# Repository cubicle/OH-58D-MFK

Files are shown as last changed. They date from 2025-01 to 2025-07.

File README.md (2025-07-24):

# OH-58D-MFK

[][cc-by-nc-sa]

<p align="center">
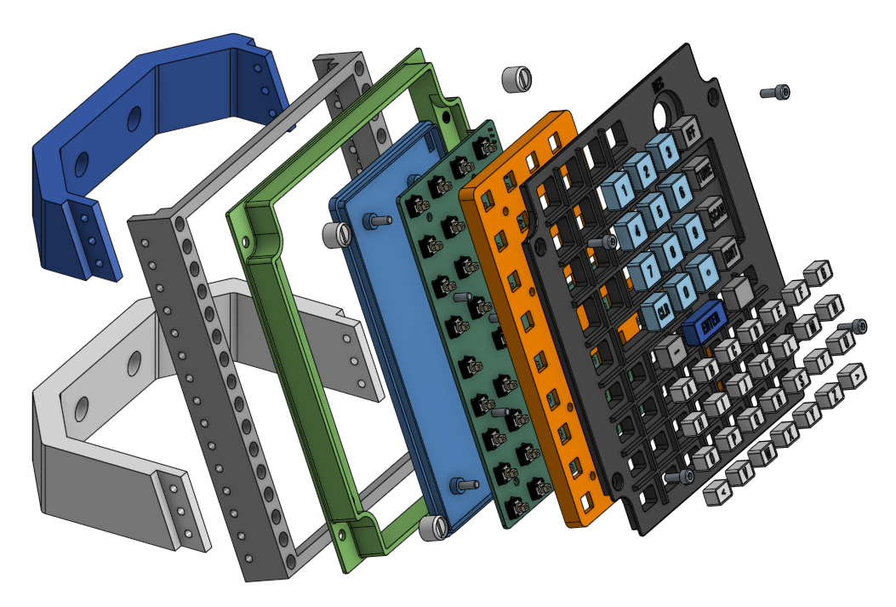
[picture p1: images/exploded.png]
Exploded view
  
</p>

## Work in progress

This project is still work in progress. Print and assemble at your own risk.

## BOM

-  1 x [Arduino Uno](https://www.amazon.de/Arduino-A000066-UNO-Rev3/dp/B008GRTSV6)
- 15 x [Heat Set Inserts M3x3 (short)](https://cnckitchen.store/products/heat-set-insert-m3-x-3-short-version-100-pieces)
-  4 x Heat Set Inserts M4
- 51 x [Diode SMD 0805 1N4148](https://www.ebay.de/itm/312738927547)
-  9 x [Resistor SMD 0805 10K](https://www.ebay.de/itm/362412320635)
- 47 x [OMRON B3F-115x Tactile Switch](https://www.ebay.de/itm/231954583799)
-  2 x [Switch cover](https://www.reichelt.de/de/de/shop/produkt/sicherheitsabdeckungen_fuer_kippschalter-105434)
-  2 x [Switch ON/OFF](https://www.pollin.de/p/kippschalter-kn3-c-101a-1-polig-on-off-420068)
-  1 x [Switch (ON)/OFF/(ON)](https://www.pollin.de/p/kippschalter-kn3-c-101a-1-polig-on-off-420068)
-  Break away pin headers
-  Wire
-  [Dupont crimping tool and connectors](https://www.amazon.de/dp/B07QX51F3B)
- 10 x Screw M3x0.50 x 8
-  5 x Screw M3x0.50 x 12

## 3D printed parts

### STLs

STLs are hosted on [Printables](https://www.printables.com/model/1201023-oh-58d-mfk).

### CAD

You can find the CAD files on [Onshape](https://cad.onshape.com/documents/6787d83c44a91f8cde39e86e/w/96151ec904b149525745d522/e/fceb9b6b394f6e8ffc93c401). Be careful as these may contain untested changes.

### Arduino Uno Case

You will need to print a case for the Arduino Uno. I used the [Arduino Uno Case](https://www.printables.com/model/122097-arduino-uno-case) from [Kazik](https://www.printables.com/@Kazik).

## License

Except where otherwise noted, this work © 2025 is licensed under a [Creative Commons Attribution-NonCommercial-ShareAlike 4.0 International License][cc-by-nc-sa].

[][cc-by-nc-sa]

[cc-by-nc-sa]: http://creativecommons.org/licenses/by-nc-sa/4.0/
[cc-by-nc-sa-image]: https://licensebuttons.net/l/by-nc-sa/4.0/88x31.png
[cc-by-nc-sa-shield]: https://img.shields.io/badge/License-CC%20BY--NC--SA%204.0-lightgrey.svg

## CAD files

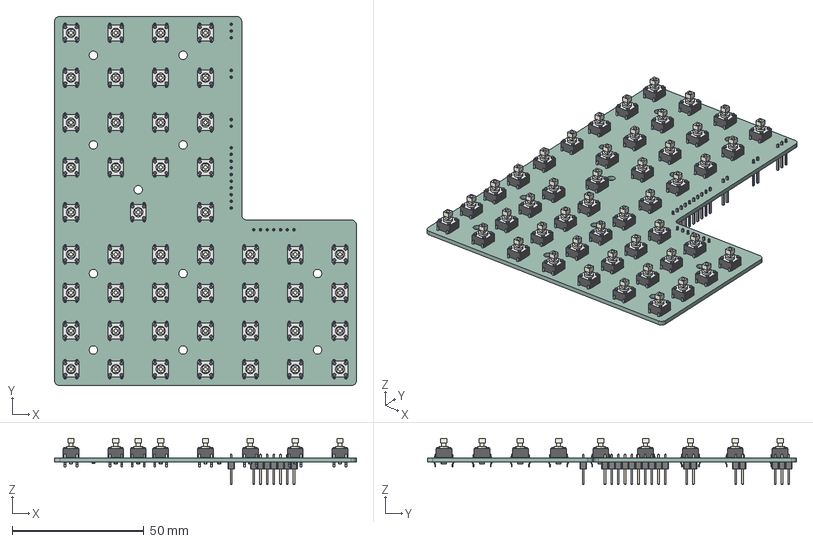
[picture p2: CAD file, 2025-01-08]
pcb/OH-58D MFK.step
114.5 x 140.0 x 17.5 mm
b3f-1050_1 x 47
D_0805 x 51
PinHeader_1x07_P254mm_Vertical
R_0805_2012Metric x 9
PinHeader_1x10_P254mm_Vertical
PinHeader_1x03_P254mm_Vertical
PinHeader_1x02_P254mm_Vertical x 2
OH-58D MFK_PCB

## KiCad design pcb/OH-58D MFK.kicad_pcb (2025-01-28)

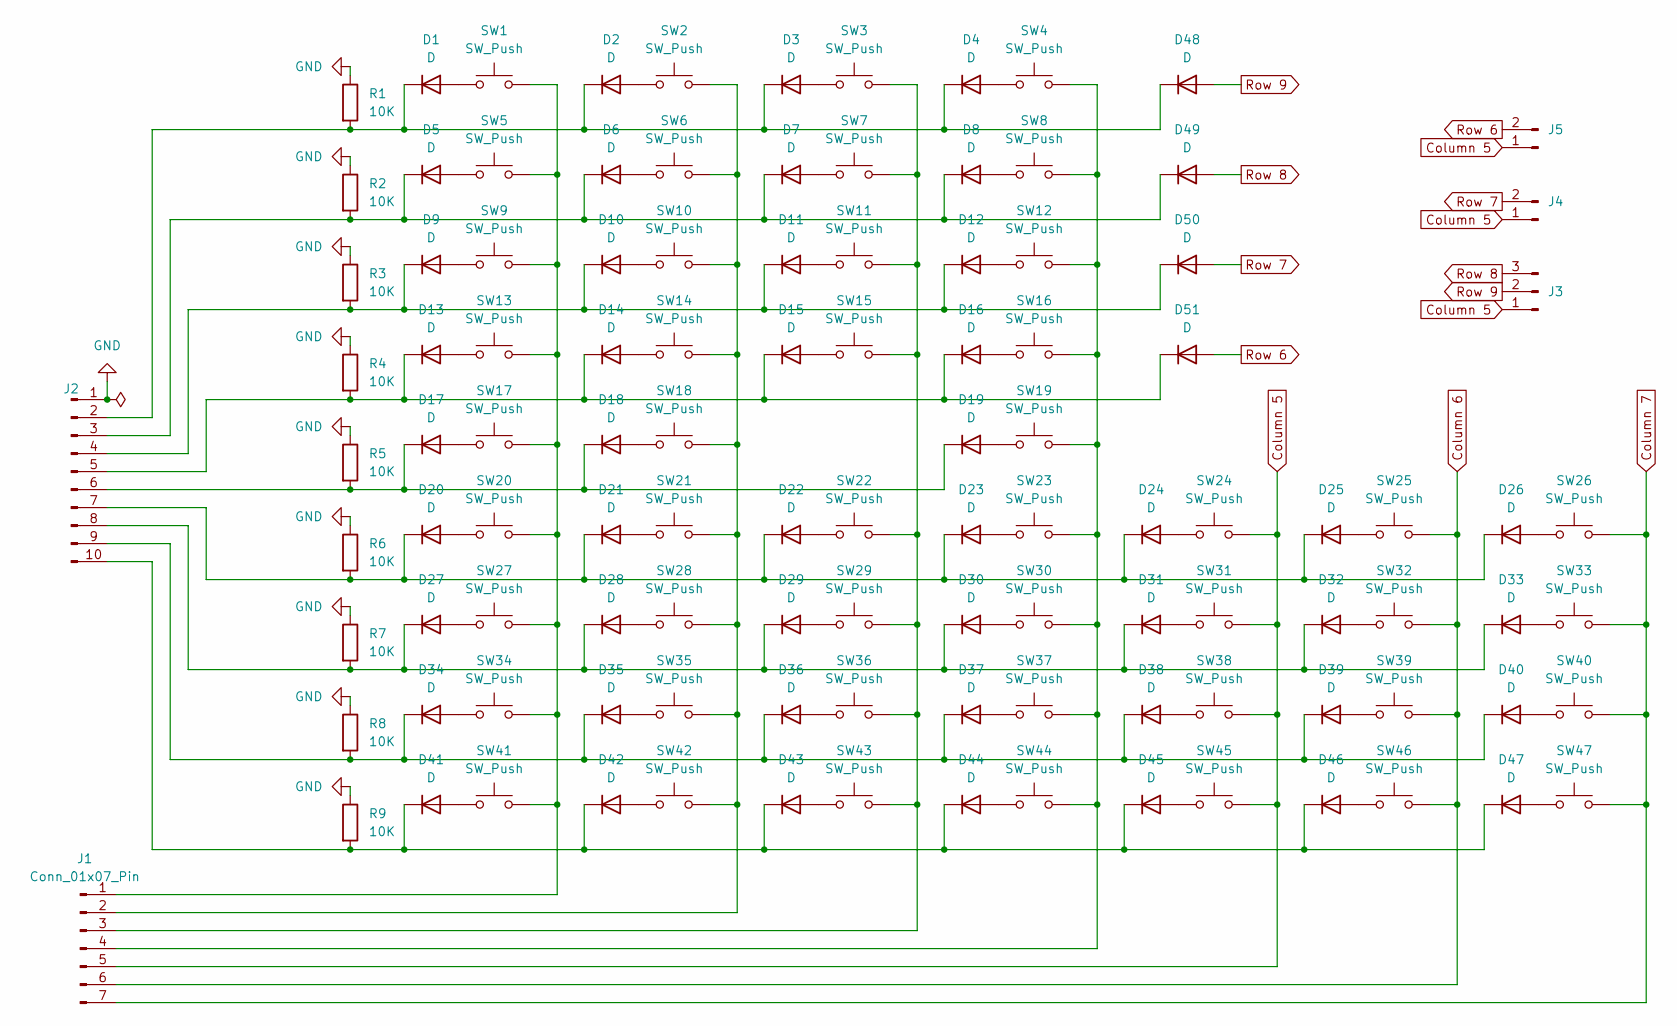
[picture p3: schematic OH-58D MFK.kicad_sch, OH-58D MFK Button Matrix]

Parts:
D1, D2, D3, D4, D5, D6, D7, D8, D9, D10, D11, D12, D13, D14, D15, D16, D17, D18, D19, D20, D21, D22, D23, D24, D25, D26, D27, D28, D29, D30, D31, D32, D33, D34, D35, D36, D37, D38, D39, D40, D41, D42, D43, D44, D45, D46, D47, D48, D49, D50, D51: D; D_0805_2012Metric_Pad1.15x1.40mm_HandSolder
J1: Conn_01x07_Pin; PinHeader_1x07_P2.54mm_Vertical
J2: Conn_01x10_Pin; PinHeader_1x10_P2.54mm_Vertical
J3: Conn_01x03_Pin; PinHeader_1x03_P2.54mm_Vertical
J4, J5: Conn_01x02_Pin; PinHeader_1x02_P2.54mm_Vertical
R1, R2, R3, R4, R5, R6, R7, R8, R9: 10K; R_0805_2012Metric_Pad1.20x1.40mm_HandSolder
SW1, SW2, SW3, SW4, SW5, SW6, SW7, SW8, SW9, SW10, SW11, SW12, SW13, SW14, SW15, SW16, SW17, SW18, SW19, SW20, SW21, SW22, SW23, SW24, SW25, SW26, SW27, SW28, SW29, SW30, SW31, SW32, SW33, SW34, SW35, SW36, SW37, SW38, SW39, SW40, SW41, SW42, SW43, SW44, SW45, SW46, SW47: SW_Push; SW_TH_Tactile_Omron_B3F-105x

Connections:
Column 5: J1.5, J3.1, J4.1, J5.1, SW24.2, SW31.2, SW38.2, SW45.2
Column 6: J1.6, SW25.2, SW32.2, SW39.2, SW46.2
Column 7: J1.7, SW26.2, SW33.2, SW40.2, SW47.2
GND: J2.1, R1.1, R2.1, R3.1, R4.1, R5.1, R6.1, R7.1, R8.1, R9.1
unnamed: D1.2 (A), SW1.1
unnamed: D1.1 (K), D2.1 (K), D3.1 (K), D4.1 (K), D48.1 (K), J2.2, R1.2
unnamed: D2.2 (A), SW2.1
unnamed: D3.2 (A), SW3.1
unnamed: D4.2 (A), SW4.1
unnamed: D5.2 (A), SW5.1
unnamed: D6.2 (A), SW6.1
unnamed: D7.2 (A), SW7.1
unnamed: D8.2 (A), SW8.1
unnamed: D9.2 (A), SW9.1
unnamed: D10.2 (A), SW10.1
unnamed: D9.1 (K), D10.1 (K), D11.1 (K), D12.1 (K), D50.1 (K), J2.4, R3.2
unnamed: D11.2 (A), SW11.1
unnamed: D12.2 (A), SW12.1
unnamed: D13.2 (A), SW13.1
unnamed: D13.1 (K), D14.1 (K), D15.1 (K), D16.1 (K), D51.1 (K), J2.5, R4.2
unnamed: D14.2 (A), SW14.1
unnamed: D15.2 (A), SW15.1
unnamed: D16.2 (A), SW16.1
unnamed: D17.2 (A), SW17.1
unnamed: D17.1 (K), D18.1 (K), D19.1 (K), J2.6, R5.2
unnamed: D18.2 (A), SW18.1
unnamed: D19.2 (A), SW19.1
unnamed: D20.2 (A), SW20.1
unnamed: D20.1 (K), D21.1 (K), D22.1 (K), D23.1 (K), D24.1 (K), D25.1 (K), D26.1 (K), J2.7, R6.2
unnamed: D21.2 (A), SW21.1
unnamed: D22.2 (A), SW22.1
unnamed: D23.2 (A), SW23.1
unnamed: D24.2 (A), SW24.1
unnamed: D25.2 (A), SW25.1
unnamed: D26.2 (A), SW26.1
unnamed: D27.2 (A), SW27.1
unnamed: D27.1 (K), D28.1 (K), D29.1 (K), D30.1 (K), D31.1 (K), D32.1 (K), D33.1 (K), J2.8, R7.2
unnamed: D28.2 (A), SW28.1
unnamed: D29.2 (A), SW29.1
unnamed: D30.2 (A), SW30.1
unnamed: D31.2 (A), SW31.1
unnamed: D32.2 (A), SW32.1
unnamed: D33.2 (A), SW33.1
unnamed: D34.2 (A), SW34.1
unnamed: D34.1 (K), D35.1 (K), D36.1 (K), D37.1 (K), D38.1 (K), D39.1 (K), D40.1 (K), J2.9, R8.2
unnamed: D35.2 (A), SW35.1
unnamed: D36.2 (A), SW36.1
unnamed: D37.2 (A), SW37.1
unnamed: D38.2 (A), SW38.1
unnamed: D39.2 (A), SW39.1
unnamed: D40.2 (A), SW40.1
unnamed: D41.2 (A), SW41.1
unnamed: D41.1 (K), D42.1 (K), D43.1 (K), D44.1 (K), D45.1 (K), D46.1 (K), D47.1 (K), J2.10, R9.2
unnamed: D42.2 (A), SW42.1
unnamed: D43.2 (A), SW43.1
unnamed: D44.2 (A), SW44.1
unnamed: D45.2 (A), SW45.1
unnamed: D46.2 (A), SW46.1
unnamed: D47.2 (A), SW47.1
unnamed: D5.1 (K), D6.1 (K), D7.1 (K), D8.1 (K), D49.1 (K), J2.3, R2.2
unnamed: J1.1, SW1.2, SW5.2, SW9.2, SW13.2, SW17.2, SW20.2, SW27.2, SW34.2, SW41.2
unnamed: J1.2, SW2.2, SW6.2, SW10.2, SW14.2, SW18.2, SW21.2, SW28.2, SW35.2, SW42.2
unnamed: J1.3, SW3.2, SW7.2, SW11.2, SW15.2, SW22.2, SW29.2, SW36.2, SW43.2
unnamed: J1.4, SW4.2, SW8.2, SW12.2, SW16.2, SW19.2, SW23.2, SW30.2, SW37.2, SW44.2
Row 6: D51.2 (A), J5.2
Row 7: D50.2 (A), J4.2
Row 8: D49.2 (A), J3.3
Row 9: D48.2 (A), J3.2

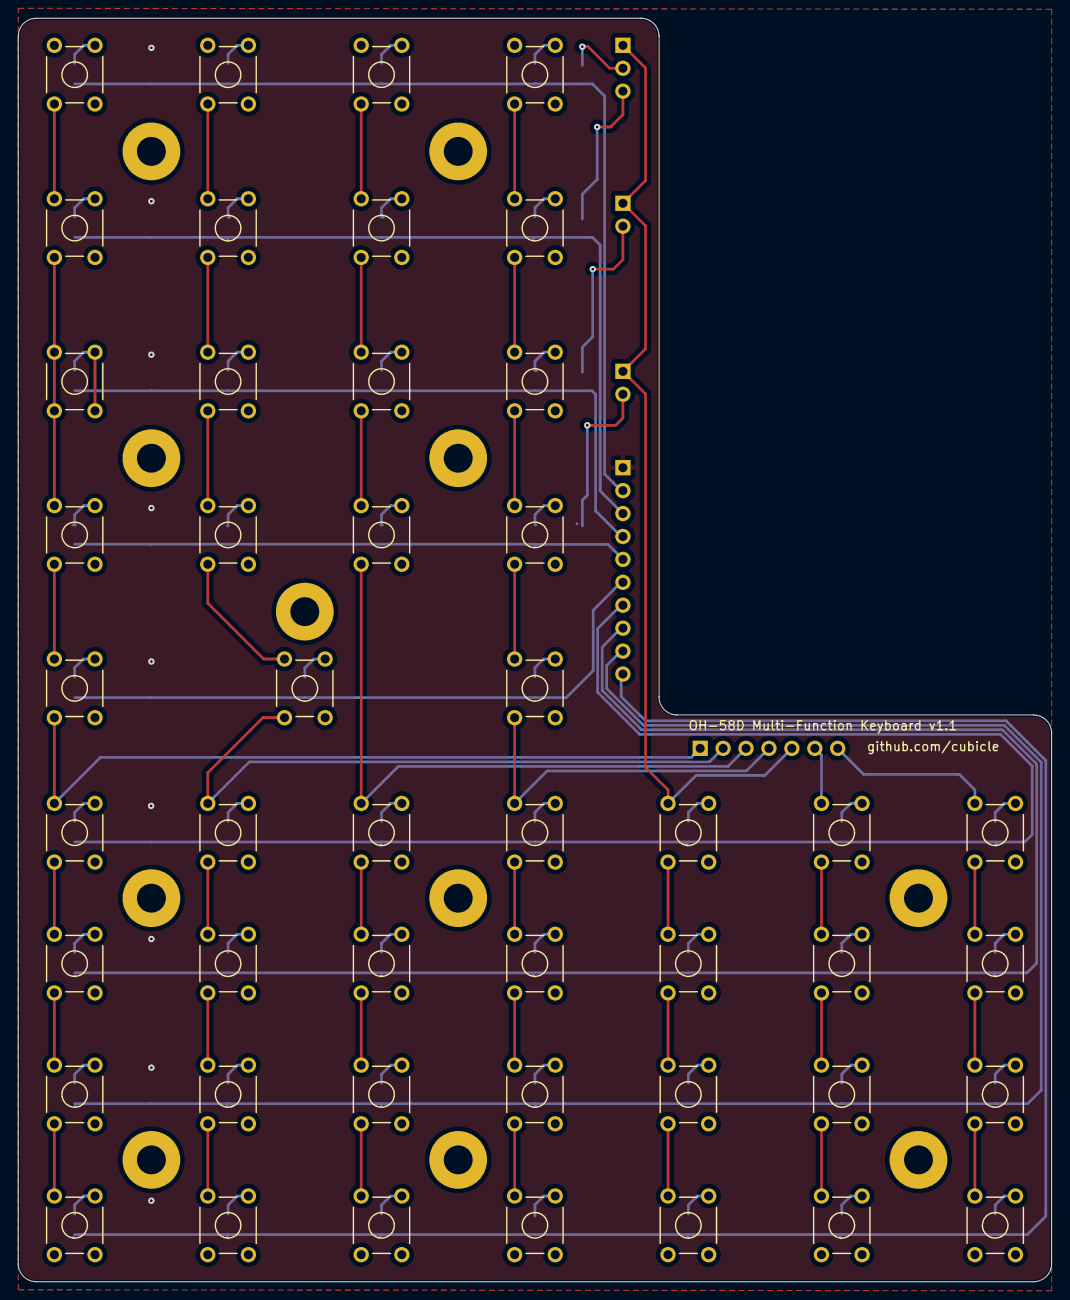
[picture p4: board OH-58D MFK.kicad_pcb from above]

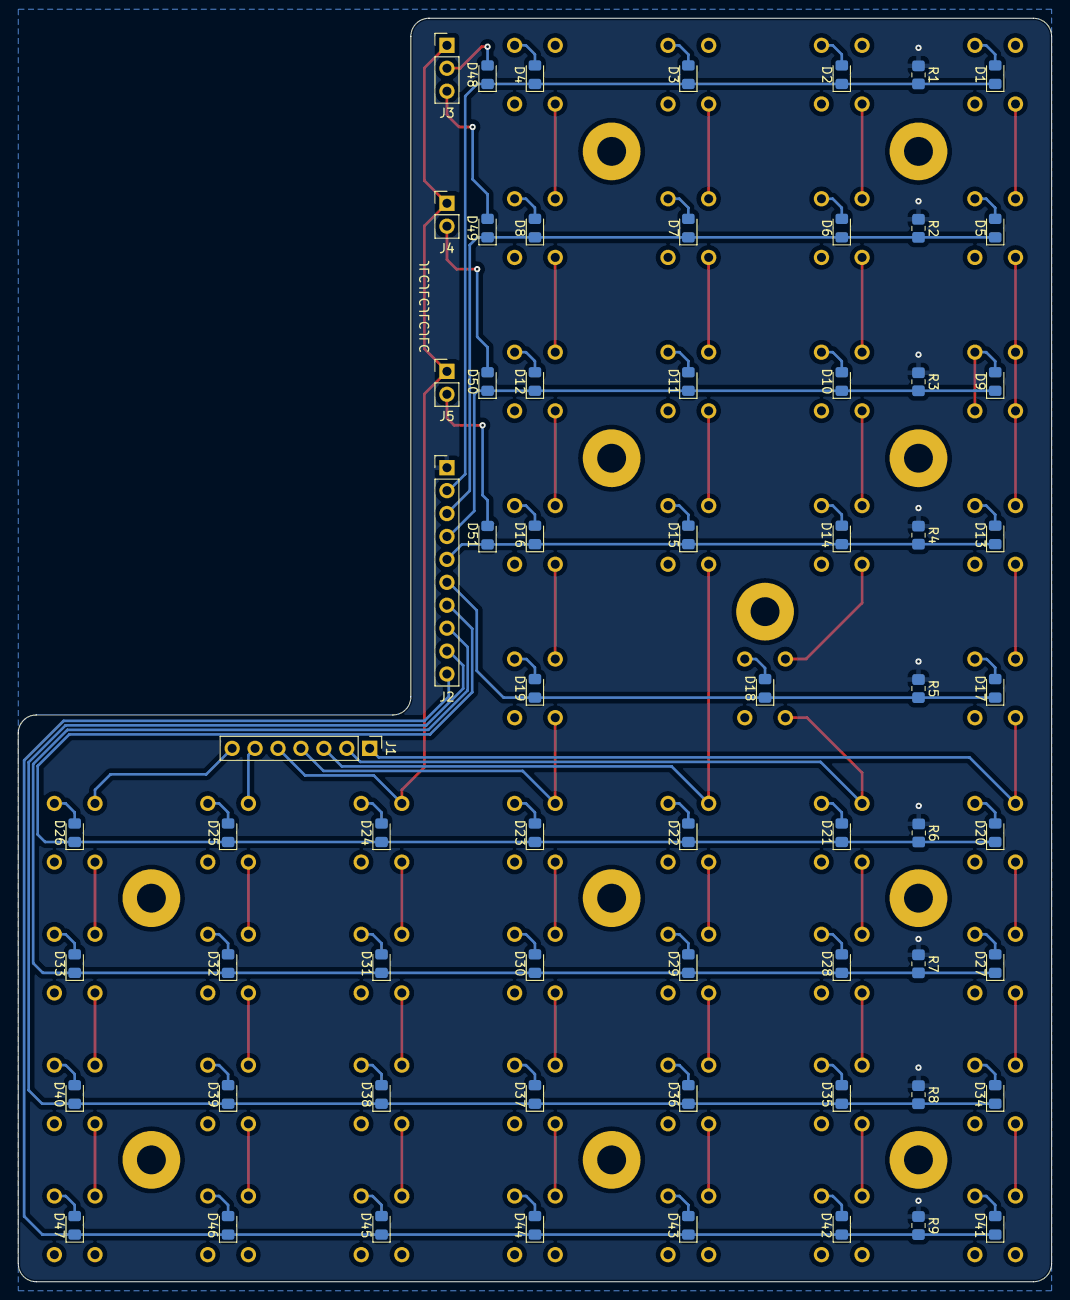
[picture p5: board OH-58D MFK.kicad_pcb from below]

Board: 2 copper layers, 114.5 x 140.0 mm, 112 parts (65 on the bottom side), 68 nets.

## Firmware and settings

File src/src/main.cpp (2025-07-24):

/**
 * Copyright © 2025 Martin Maaß
 * 
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
 * You should have received a copy of the GNU General Public License along with the OH-58D MFK. If not, see 
 * <https://www.gnu.org/licenses/>.
 */
#define DCSBIOS_DISABLE_SERVO
#define DCSBIOS_DEFAULT_SERIAL
#include <DcsBios.h>
#include <Arduino.h>
#include <MatSwitch3Pos.h>
#include <MatSwitchWithCover2PosT.h>

// #define DEBUG true

static const uint8_t MATRIX_COLUMN_COUNT = 7;
static const uint8_t MATRIX_ROW_COUNT    = 9;

static const uint8_t PIN_COL_1 = 2;
static const uint8_t PIN_COL_2 = 3;
static const uint8_t PIN_COL_3 = 4;
static const uint8_t PIN_COL_4 = 5;
static const uint8_t PIN_COL_5 = 6;
static const uint8_t PIN_COL_6 = 7;
static const uint8_t PIN_COL_7 = 8;

static const uint8_t PIN_ROW_1 = 9;
static const uint8_t PIN_ROW_2 = 10;
static const uint8_t PIN_ROW_3 = 11;
static const uint8_t PIN_ROW_4 = 12;
static const uint8_t PIN_ROW_5 = 13;
static const uint8_t PIN_ROW_6 = A0;
static const uint8_t PIN_ROW_7 = A1;
static const uint8_t PIN_ROW_8 = A2;
static const uint8_t PIN_ROW_9 = A3;

static const int COLUMN_PINS[MATRIX_COLUMN_COUNT] = {
  PIN_COL_1,
  PIN_COL_2,
  PIN_COL_3,
  PIN_COL_4,
  PIN_COL_5,
  PIN_COL_6,
  PIN_COL_7
};

static const int ROW_PINS[MATRIX_ROW_COUNT] = {
  PIN_ROW_1,
  PIN_ROW_2,
  PIN_ROW_3,
  PIN_ROW_4,
  PIN_ROW_5,
  PIN_ROW_6,
  PIN_ROW_7,
  PIN_ROW_8,
  PIN_ROW_9
};

volatile unsigned char matrix[MATRIX_COLUMN_COUNT][MATRIX_ROW_COUNT] = {
  0, 0, 0, 0, 0, 0, 0,
  0, 0, 0, 0, 0, 0, 0,
  0, 0, 0, 0, 0, 0, 0,
  0, 0, 0, 0, 0, 0, 0,
  0, 0, 0, 0, 0, 0, 0,
  0, 0, 0, 0, 0, 0, 0,
  0, 0, 0, 0, 0, 0, 0,
  0, 0, 0, 0, 0, 0, 0,
  0, 0, 0, 0, 0, 0, 0,
};

DcsBios::MatActionButtonSet mfk1("MFK_1", &matrix[6][0], HIGH);
DcsBios::MatActionButtonSet mfk2("MFK_2", &matrix[5][0], HIGH);
DcsBios::MatActionButtonSet mfk3("MFK_3", &matrix[4][0], HIGH);
DcsBios::MatActionButtonSet mfkIFF("MFK_IFF", &matrix[3][0], HIGH);

DcsBios::MatActionButtonSet mfk4("MFK_4", &matrix[6][1], HIGH);
DcsBios::MatActionButtonSet mfk5("MFK_5", &matrix[5][1], HIGH);
DcsBios::MatActionButtonSet mfk6("MFK_6", &matrix[4][1], HIGH);
DcsBios::MatActionButtonSet mfkTune("MFK_TUNE", &matrix[3][1], HIGH);

DcsBios::MatActionButtonSet mfk7("MFK_7", &matrix[6][2], HIGH);
DcsBios::MatActionButtonSet mfk8("MFK_8", &matrix[5][2], HIGH);
DcsBios::MatActionButtonSet mfk9("MFK_9", &matrix[4][2], HIGH);
DcsBios::MatActionButtonSet mfkScan("MFK_SCAN", &matrix[3][2], HIGH);

DcsBios::MatActionButtonSet mfkClr("MFK_CLR", &matrix[6][3], HIGH);
DcsBios::MatActionButtonSet mfk0("MFK_0", &matrix[5][3], HIGH);
DcsBios::MatActionButtonSet mfkDot("MFK_DOT", &matrix[4][3], HIGH);
//DcsBios::MatActionButtonSet mfk?("MFK_?", &matrix[3][3], HIGH);
DcsBios::MatActionButtonSet mfkMinus("MFK_MINUS", &matrix[6][4], HIGH);
DcsBios::MatActionButtonSet mfkEnter("MFK_ENTER", &matrix[5][4], HIGH);
DcsBios::MatActionButtonSet mfkIdnt("MFK_IDNT", &matrix[3][4], HIGH);

MatSwitch3Pos mfkAcknowledgeRecall("MFK_ACKNOWLEDGE_RECALL", &matrix[2][0], &matrix[2][1]);
MatSwitchWithCover2Pos mfkZeroize("MFK_ZEROIZE", "MFK_ZEROIZE_COVER", &matrix[2][3], true);
MatSwitchWithCover2Pos mfkEmergency("MFK_EMERGENCY", "MFK_EMERGENCY_COVER",  &matrix[2][2], true);

DcsBios::MatActionButtonSet mfkA("MFK_A", &matrix[6][5], HIGH);
DcsBios::MatActionButtonSet mfkB("MFK_B", &matrix[5][5], HIGH);
DcsBios::MatActionButtonSet mfkC("MFK_C", &matrix[4][5], HIGH);
DcsBios::MatActionButtonSet mfkD("MFK_D", &matrix[3][5], HIGH);
DcsBios::MatActionButtonSet mfkE("MFK_E", &matrix[2][5], HIGH);
DcsBios::MatActionButtonSet mfkF("MFK_F", &matrix[1][5], HIGH);
DcsBios::MatActionButtonSet mfkG("MFK_G", &matrix[0][5], HIGH);

DcsBios::MatActionButtonSet mfkH("MFK_H", &matrix[6][6], HIGH);
DcsBios::MatActionButtonSet mfkI("MFK_I", &matrix[5][6], HIGH);
DcsBios::MatActionButtonSet mfkJ("MFK_J", &matrix[4][6], HIGH);
DcsBios::MatActionButtonSet mfkK("MFK_K", &matrix[3][6], HIGH);
DcsBios::MatActionButtonSet mfkL("MFK_L", &matrix[2][6], HIGH);
DcsBios::MatActionButtonSet mfkM("MFK_M", &matrix[1][6], HIGH);
DcsBios::MatActionButtonSet mfkN("MFK_N", &matrix[0][6], HIGH);

DcsBios::MatActionButtonSet mfkO("MFK_O", &matrix[6][7], HIGH);
DcsBios::MatActionButtonSet mfkP("MFK_P", &matrix[5][7], HIGH);
DcsBios::MatActionButtonSet mfkQ("MFK_Q", &matrix[4][7], HIGH);
DcsBios::MatActionButtonSet mfkR("MFK_R", &matrix[3][7], HIGH);
DcsBios::MatActionButtonSet mfkS("MFK_S", &matrix[2][7], HIGH);
DcsBios::MatActionButtonSet mfkT("MFK_T", &matrix[1][7], HIGH);
DcsBios::MatActionButtonSet mfkU("MFK_U", &matrix[0][7], HIGH);

DcsBios::MatActionButtonSet mfkArrowLeft("MFK_ARROW_LEFT",  &matrix[6][8], HIGH);
DcsBios::MatActionButtonSet mfkV("MFK_V", &matrix[5][8], HIGH);
DcsBios::MatActionButtonSet mfkW("MFK_W", &matrix[4][8], HIGH);
DcsBios::MatActionButtonSet mfkX("MFK_X", &matrix[3][8], HIGH);
DcsBios::MatActionButtonSet mfkY("MFK_Y", &matrix[2][8], HIGH);
DcsBios::MatActionButtonSet mfkZ("MFK_Z", &matrix[1][8], HIGH);
DcsBios::MatActionButtonSet mfkArrowRight("MFK_ARROW_RIGHT", &matrix[0][8], HIGH);


void setup() {
  #ifdef DEBUG
  Serial.begin(9600);
  #else
  DcsBios::setup();
  #endif

  // configure output pins for each col
  pinMode(PIN_COL_1, OUTPUT);
  pinMode(PIN_COL_2, OUTPUT);
  pinMode(PIN_COL_3, OUTPUT);
  pinMode(PIN_COL_4, OUTPUT);
  pinMode(PIN_COL_5, OUTPUT);
  pinMode(PIN_COL_6, OUTPUT);
  pinMode(PIN_COL_7, OUTPUT);

  pinMode(PIN_ROW_1, INPUT);
  pinMode(PIN_ROW_2, INPUT);
  pinMode(PIN_ROW_3, INPUT);
  pinMode(PIN_ROW_4, INPUT);
  pinMode(PIN_ROW_5, INPUT);
  pinMode(PIN_ROW_6, INPUT);
  pinMode(PIN_ROW_7, INPUT);
  pinMode(PIN_ROW_8, INPUT);
  pinMode(PIN_ROW_9, INPUT);
}

void loop() {

  // scan the matrix
  for (int column = 0; column < MATRIX_COLUMN_COUNT; column++) {
    
    digitalWrite(COLUMN_PINS[column], HIGH);

    // we use a direct mapping from row to input pin
    for (int row = 0; row < MATRIX_ROW_COUNT; row++) {
      if (digitalRead(ROW_PINS[row])) {
        #ifdef DEBUG
        if (matrix[column][row] == 0) {
          Serial.print(column);
          Serial.print(", ");
          Serial.print(row);
          Serial.println(" pressed.");
        }
        #endif
        matrix[column][row] = 1;
      } else {
        matrix[column][row] = 0;
      }
    }
    digitalWrite(COLUMN_PINS[column], LOW);
  }
  #ifndef DEBUG
  DcsBios::loop();
  #endif
}

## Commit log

2025-01-08 Initial PCB design 🚀
    [OH-58D MFK.kicad_pcb, OH-58D MFK.kicad_sch, OH-58D MFK.step]
2025-01-28 Add missing trace for D44 (#2)
    [OH-58D MFK.kicad_pcb]
2025-01-28 Raise PCB revision to 1.1
    [OH-58D MFK.kicad_pcb]
2025-02-01 Add basic BOM to README (#3)
2025-02-21 Add link to Printables project to README
2025-07-24 Port code to be run on an Arduino Uno.
2025-07-24 Update BOM for v2.0
2025-07-24 Adds download instructions for the Arduino Uno case.

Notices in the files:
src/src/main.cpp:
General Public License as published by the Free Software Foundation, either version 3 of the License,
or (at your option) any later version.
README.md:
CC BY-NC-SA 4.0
